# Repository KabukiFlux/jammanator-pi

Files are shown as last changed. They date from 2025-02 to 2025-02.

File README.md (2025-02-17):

# Raspberry pi jamma bard "jammanator"

<b align="center">Jammanator, the Raspberry Pi JAMMA output board 
for your cabinet</b>

## Table of contents

- [Why](#why)
- [Description](#description)
- [Schematics](#schematics)
- [Install](#install)
- [Pics and final result](#pics-and-final-result)

## Why?

This was done during some live events on Twitch.tv and tested for some time.

This is a very old design for Raspberry Pi 3B+, 4, 400, it no longer 
has the status that anybody can make money and make profit of it 
so I decided to publish it, if you have an arcade cabinet with JAMMA
a spare Raspberry Pi 3B+ or 4 and you want to have something running
then is a matter of burning the rgbpiOS or the recalboxOS and you have
everything you need to make it work.

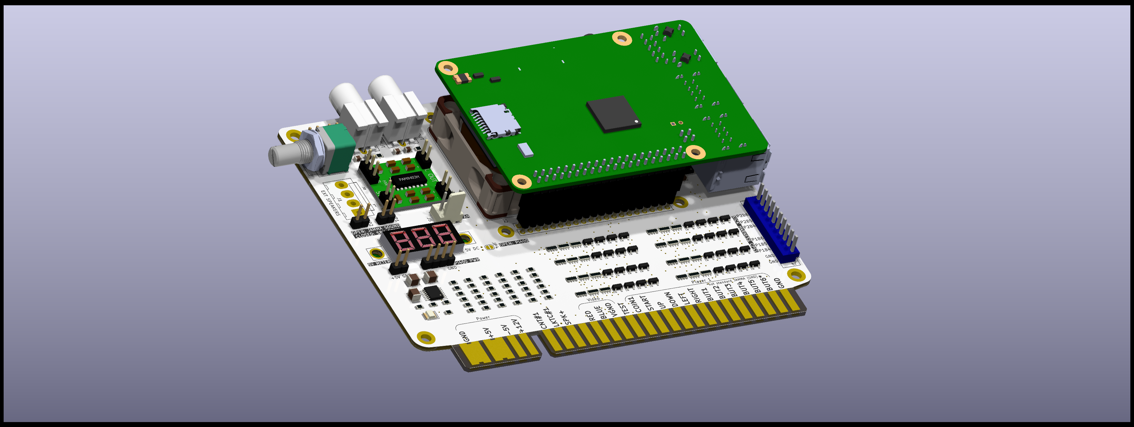
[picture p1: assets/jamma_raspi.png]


## Description

This board is intended to be a PCB used with a Raspberry Pi and a 4x4 5v fan
to remove some heat from the CPU.

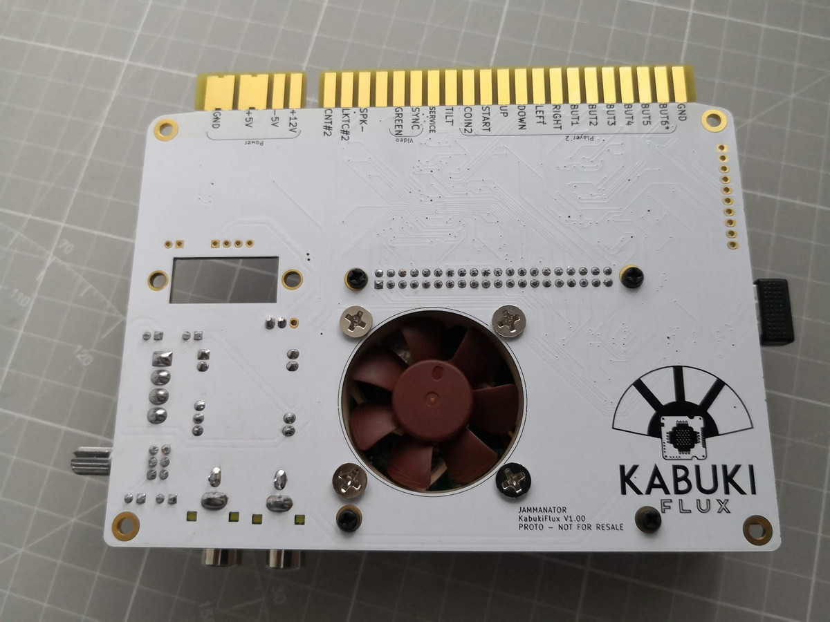
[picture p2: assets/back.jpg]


This board uses 2 I2C parallel expansion I/O chips connected to the JAMMA
connector in order to map automatically the buttons to the cabinet with no
configuration required.

A voltmeter has been added to check the 5v rail while running.

A protection circuit has been mapped to all the inputs and an extra buffer
to avoid any loss of the I2C bus, if the I2C bus is lost the Raspberry will 
no longer boot the OS (yellow led) this design will avoid that.

In the BOM directory there's an interactive BOM with all the required components.

In the gerbers directory we have the gerbers to manufacture the boards.

In the KiCAD folder we can find the KiCAD project itself.

In the circuit_js folder you can find the simulation for the I/O protection.

## Schematics

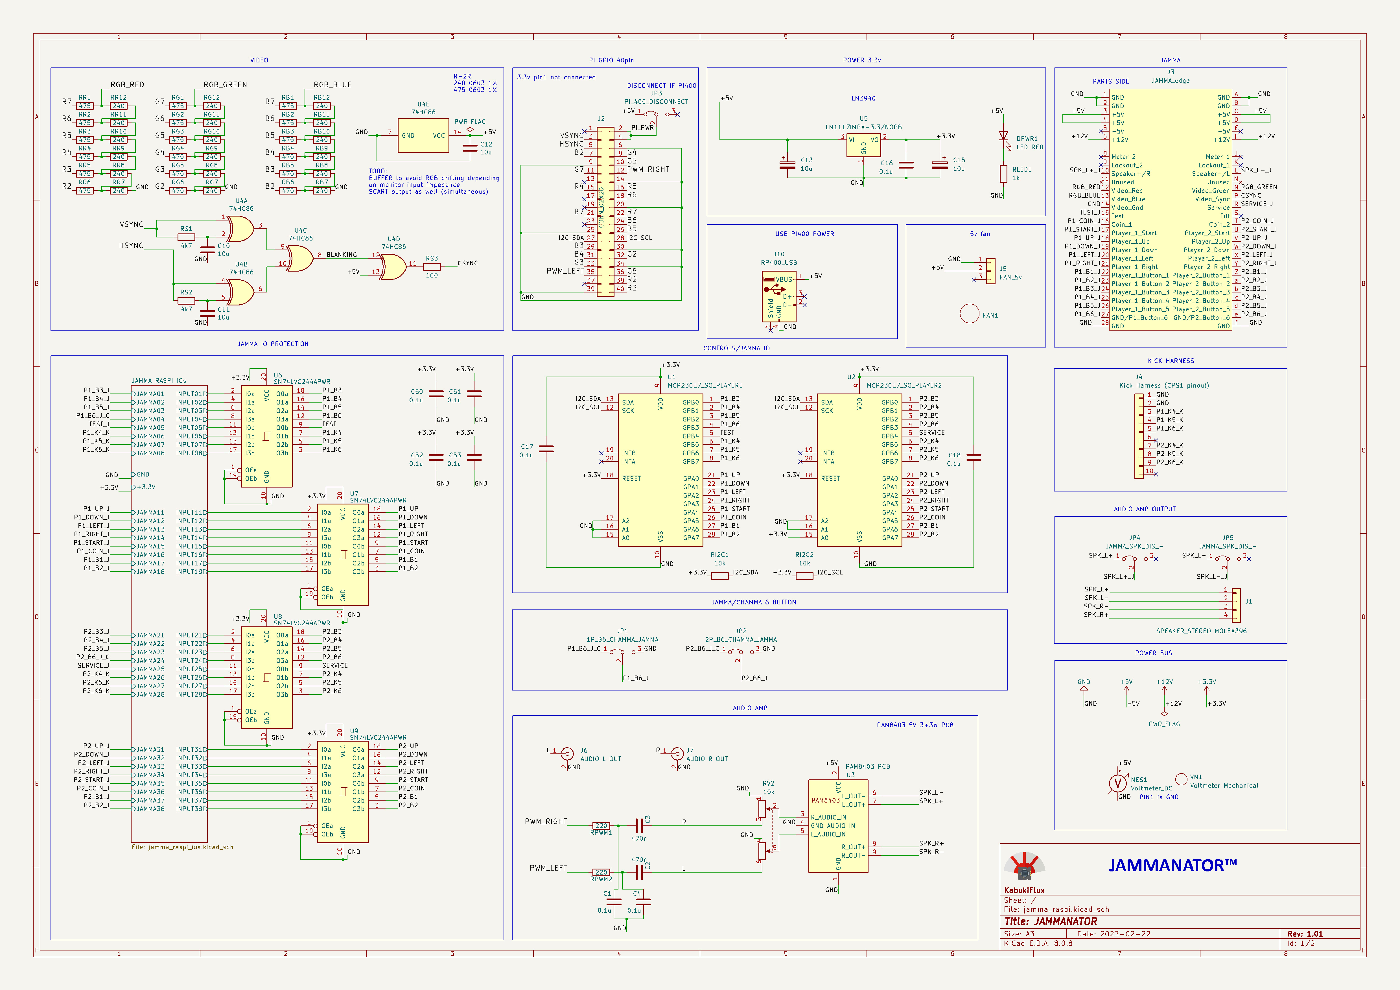
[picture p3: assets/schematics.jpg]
Schematics


This is the schematics.

## Install

If you use a Raspberry Pi 400 (the one with the keyboard) I recommend this
board and the extender in order to use it (check carefully the connector position):

- [GPIO board](https://www.amazon.es/IBest-Waveshare-Raspberry-Color-Coded-Expansion/dp/B08SK71PB4)

- [Extension cable](https://www.amazon.es/vhbw-extensi%C3%B3n-compatible-Raspberry-miniordenador/dp/B0B94KRZ8Z)

Ensure the RP400 pin is in the right position, as the RP400 cannot be powered
via the GPIO we must provide USB-C power and avoid sending power to the GPIO.

1- Send to manufacture the GERBER board to [JLCPCB](https://jlcpcb.com/) or other PCB manufacturer.

2- Get the components required, you can see here the Bill Of Materials [BOM](bom/ibom.html)

3- Solder the components.

4- Connect a Raspberry Pi with [rgbpi-OS](https://ko-fi.com/s/4119fb48b8) or 
[recalbox-OS](https://www.recalbox.com/es/download/stable/rpi/)

5- Follow the installation guide and instructions for the selected OS. 

Once finished you should have something like this:

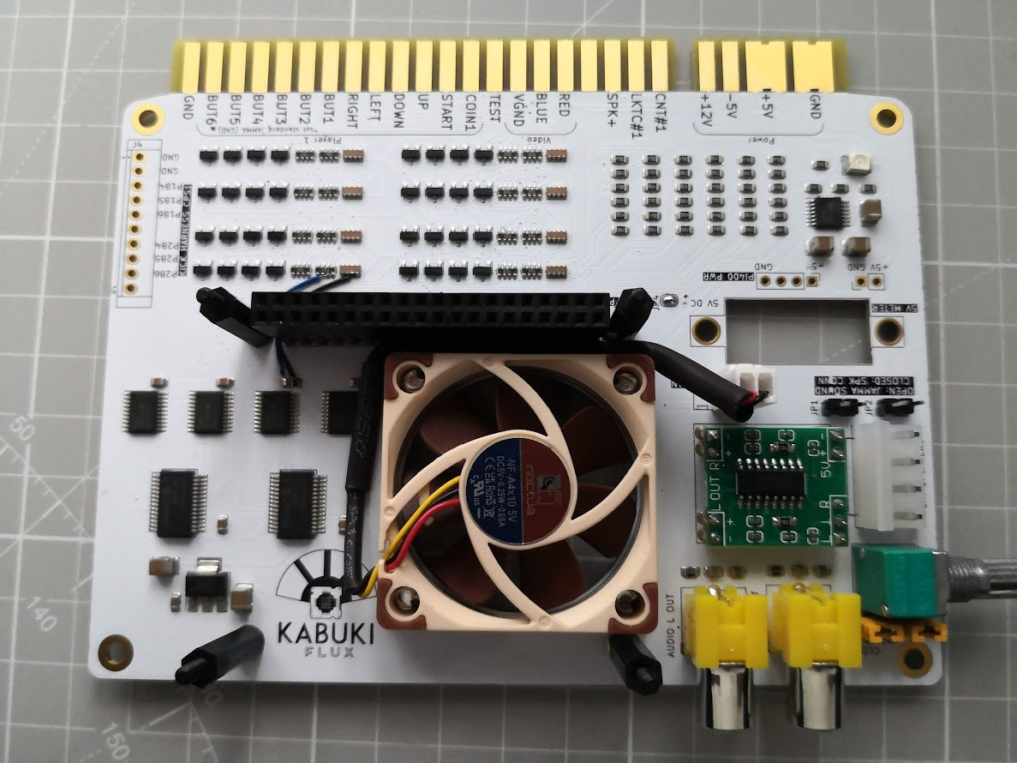
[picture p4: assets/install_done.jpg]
Install done


### Pics and final result

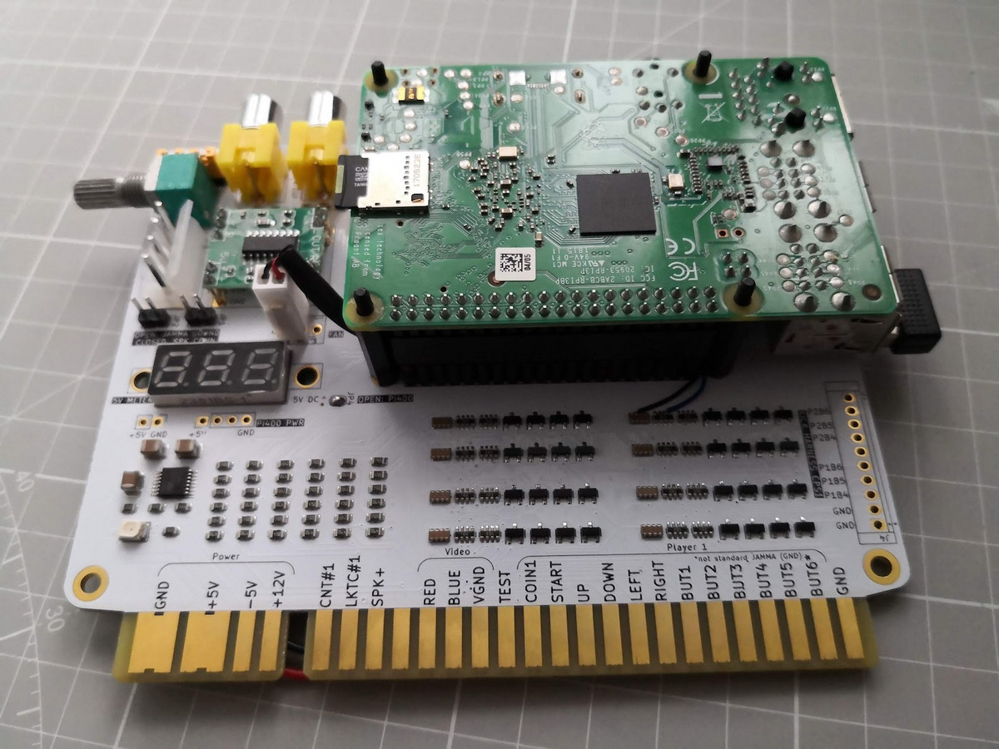
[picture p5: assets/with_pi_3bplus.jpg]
Finished


I'm not responsible
============
And yes, read below, no liability is assumed for misuse.

DISCLAIMER (See Licensing)
==========================
See LICENSE fo more information.

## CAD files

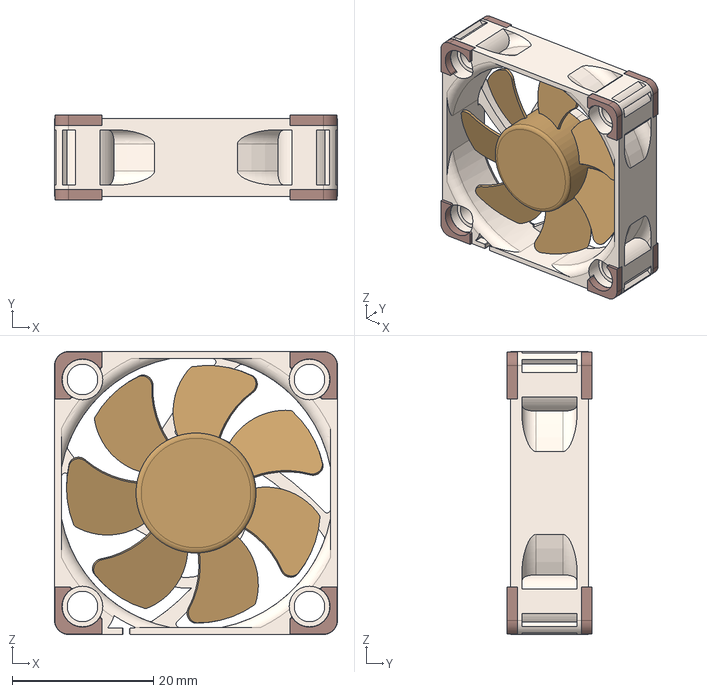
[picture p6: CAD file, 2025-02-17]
kicad/3D/Noctua_NF-A4x10_40mm.step
40.1 x 12.0 x 40.1 mm
Noctua-NF-A4x10 v1
Noctua nf-a8-pwm fan 80x80x25 v2

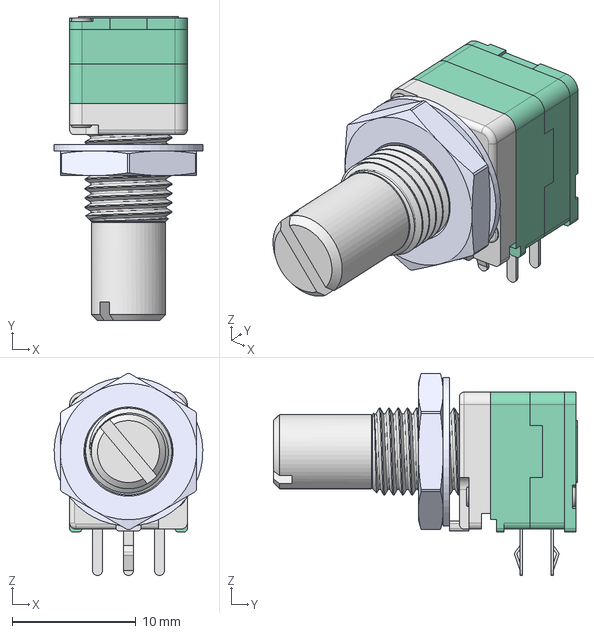
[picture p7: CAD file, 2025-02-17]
kicad/3D/RK0972-L-15RE_N-7-green.step
12.0 x 24.6 x 16.3 mm

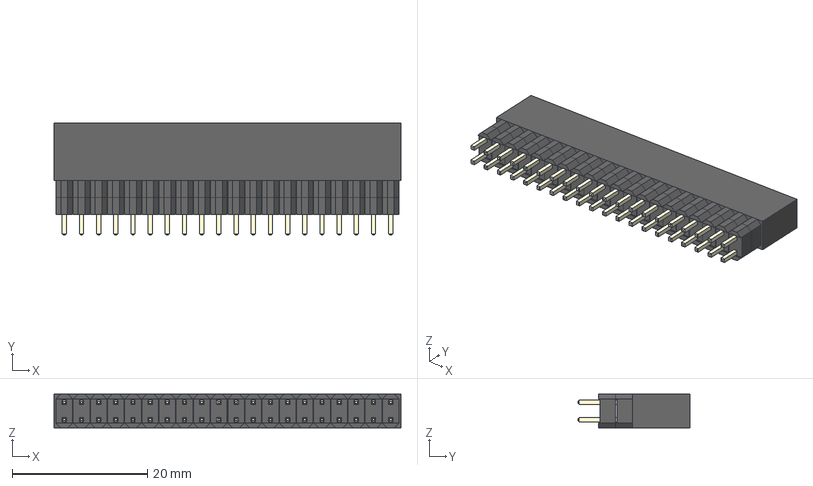
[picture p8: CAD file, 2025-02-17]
kicad/3D/PRT-14017_2x20_tall_header.stp
51.3 x 16.5 x 5.00 mm

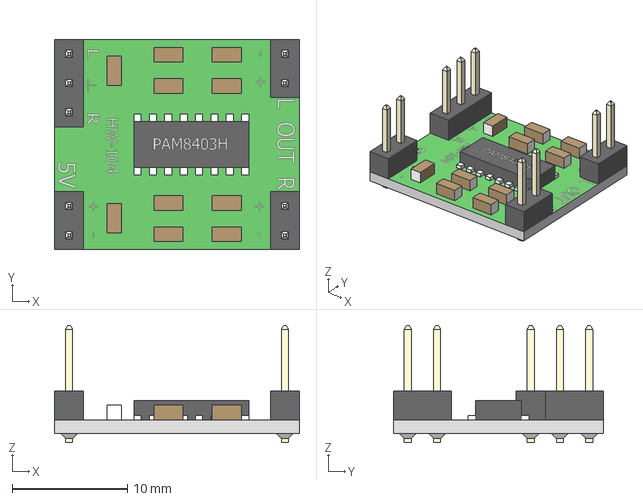
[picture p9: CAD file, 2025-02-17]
kicad/3D/Sound-Aplifier-Board-PAM8403-3W.stp
21.3 x 18.3 x 10.2 mm

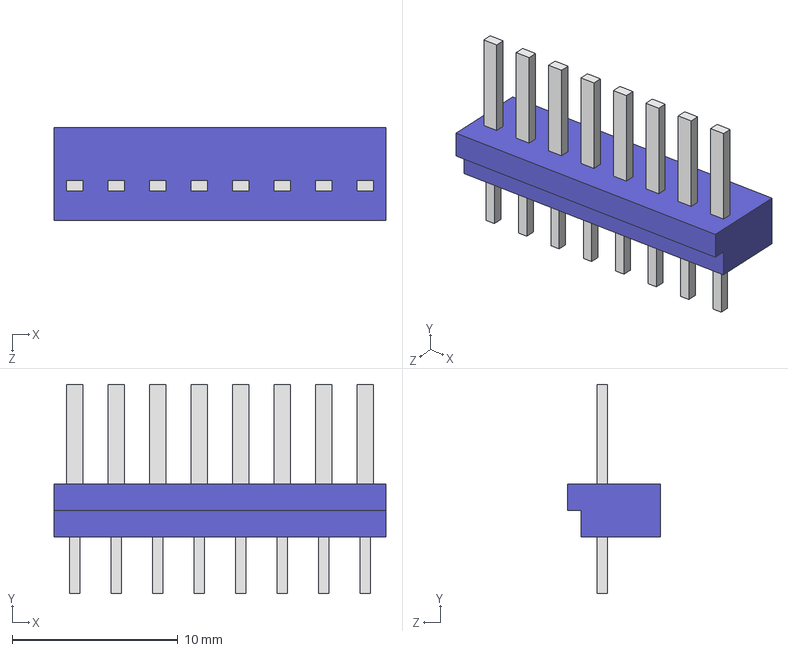
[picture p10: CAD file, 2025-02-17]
kicad/3D/B8P-SHF-1AA.STEP
20.0 x 12.6 x 5.60 mm

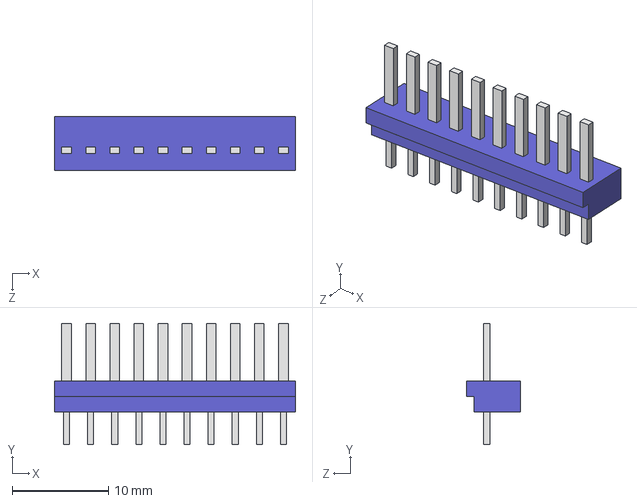
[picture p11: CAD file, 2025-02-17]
kicad/3D/B10P-SHF-1AA.STEP
25.0 x 12.6 x 5.60 mm

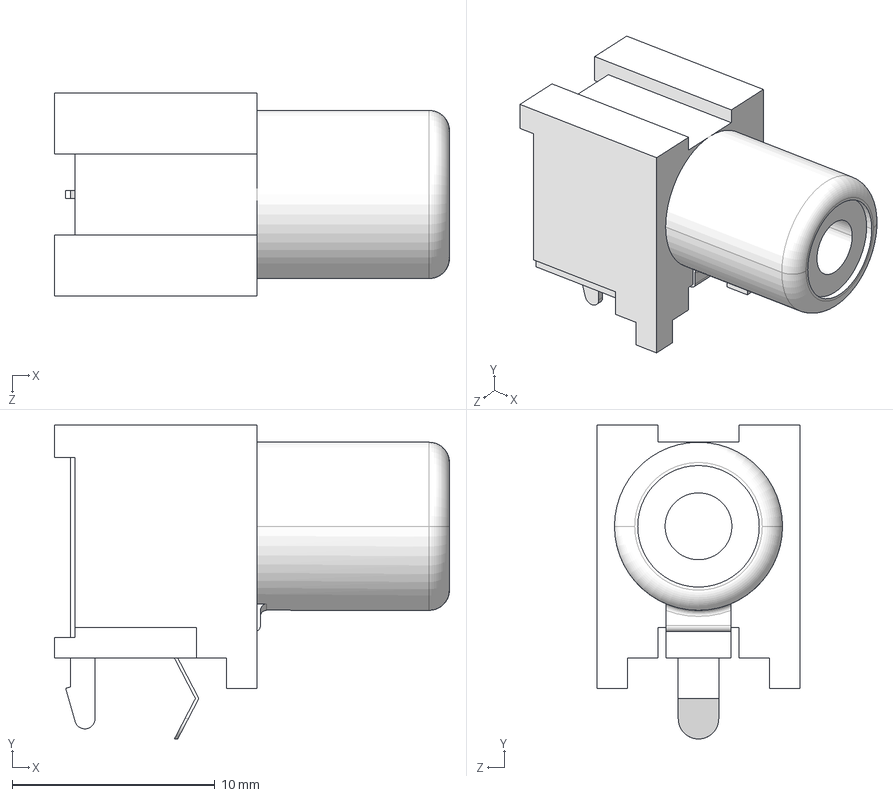
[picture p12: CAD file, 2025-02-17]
kicad/3D/CUI_DEVICES_RCJ-043.step
19.5 x 15.5 x 10.0 mm

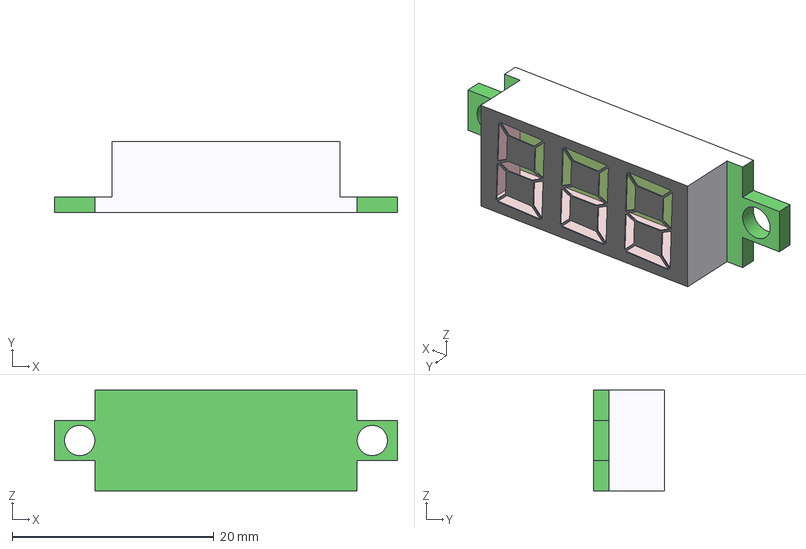
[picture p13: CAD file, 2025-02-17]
kicad/3D/Voltage_Indicator.stp
34.0 x 7.00 x 10.0 mm

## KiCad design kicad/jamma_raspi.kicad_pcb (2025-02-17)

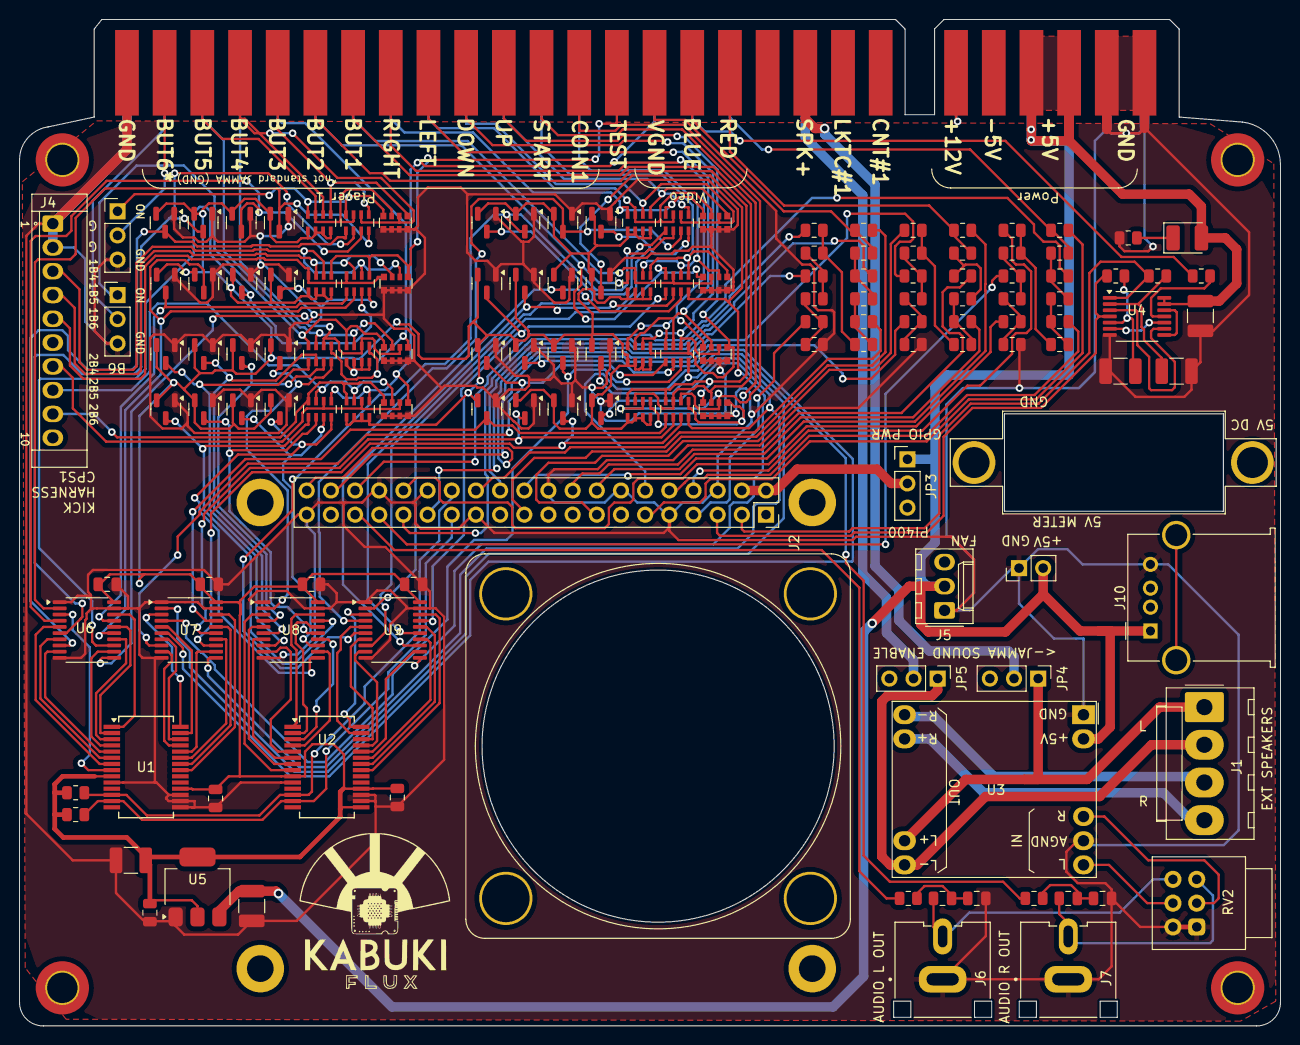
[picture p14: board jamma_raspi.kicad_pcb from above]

Board: 2 copper layers, 132.5 x 105.7 mm, 149 parts (1 on the bottom side), 165 nets.

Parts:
C1, C4, C16, C17, C18, C50, C51, C52, C53: 0.1u; C_0805_2012Metric
C2, C3: 470n; C_0805_2012Metric
C10, C11, C12, C13, C15: 10u; C_1210_3225Metric_Pad1.33x2.70mm_HandSolder
CN1, CN2, CN3, CN4, CN5, CN6, CN7, CN8: 100n; C_Array_Convex_4x0612
D1, D2, D3, D4, D5, D6, D7, D8, D9, D10, D11, D12, D13, D14, D15, D16, D17, D18, D19, D20, D21, D22, D23, D24, D25, D26, D27, D28, D29, D30, D31, D32: BAT54S; SOT-23
DPWR1: LED RED; LED_1210_3225Metric_Pad1.42x2.65mm_HandSolder
FAN1: Noctua_NF-A4x10_40mm
G1: LOGO; LogoKabuki_18mm
G2: LOGO; LogoKabuki
J1: SPEAKER_STEREO MOLEX396; Molex_KK-396_A-41791-0004_1x04_P3.96mm_Vertical
J2: CONN_02X20; GPIO_2x20_P2.54mm_Vertical_Tall_w_Standoffs
J3: JAMMA_edge
J4: Kick Harness (CPS1 pinout); B10P-SHF-1AA
J5: FAN_5v; Molex_KK-254_AE-6410-03A_1x03_P2.54mm_Vertical
J6: AUDIO L OUT; CUI_RCJ-043
J7: AUDIO R OUT; CUI_RCJ-043
J10: RP400_USB; USB_A_Molex_67643_Horizontal
JP1: 1P_B6_CHAMMA_JAMMA; PinHeader_1x03_P2.54mm_Vertical
JP2: 2P_B6_CHAMMA_JAMMA; PinHeader_1x03_P2.54mm_Vertical
JP3: PI_400_DISCONNECT; PinHeader_1x03_P2.54mm_Vertical
JP4: JAMMA_SPK_DIS_+; PinHeader_1x03_P2.54mm_Vertical
JP5: JAMMA_SPK_DIS_-; PinHeader_1x03_P2.54mm_Vertical
M1, M2, M3, M4: MountingHole_3.2mm_M3_DIN965_Pad_TopBottom
MES1: Voltmeter_DC; PinHeader_1x02_P2.54mm_Vertical
RB1, RB2, RB3, RB4, RB5, RB6: 475; R_0805_2012Metric
RB7, RB8, RB9, RB10, RB11, RB12: 240; R_0805_2012Metric
RG1, RG2, RG3, RG4, RG5, RG6: 475; R_0805_2012Metric
RG7, RG8, RG9, RG10, RG11, RG12: 240; R_0805_2012Metric
RI2C1, RI2C2: 10k; R_0805_2012Metric
RLED1: 1k; R_0805_2012Metric
RN1, RN3, RN5, RN7, RN9, RN11, RN13, RN15: 1k; R_Array_Concave_4x0603
RN2, RN4, RN6, RN8, RN10, RN12, RN14, RN16: 10k; R_Array_Concave_4x0603
RPWM1, RPWM2: 220; R_0805_2012Metric
RR1, RR2, RR3, RR4, RR5, RR6: 475; R_0805_2012Metric
RR7, RR8, RR9, RR10, RR11, RR12: 240; R_0805_2012Metric
RS1, RS2: 4k7; R_0805_2012Metric
RS3: 100; R_0805_2012Metric
RV2: 10k; Potentiometer_Alps_RK097_Dual_Horizontal
U1: MCP23017_SO_PLAYER1; SSOP-28_5.3x10.2mm_P0.65mm
U2: MCP23017_SO_PLAYER2; SSOP-28_5.3x10.2mm_P0.65mm
U3: PAM8403 PCB; PAM8403_module
U4: 74HC86; TSSOP-14_4.4x5mm_P0.65mm
U5: LM1117IMPX-3.3/NOPB; SOT-223-3_TabPin2
U6, U7, U8, U9: SN74LVC244APWR; TSSOP-20_4.4x6.5mm_P0.65mm
VM1: Voltmeter Mechanical; voltmeter

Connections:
+3.3V: C15.1, C16.1, C17.1, C18.1, C50.1, C51.1, C52.1, C53.1, D1.2 (K), D2.2 (K), D3.2 (K), D4.2 (K), D5.2 (K), D6.2 (K), D7.2 (K), D8.2 (K), D9.2 (K), D10.2 (K), D11.2 (K), D12.2 (K), D13.2 (K), D14.2 (K), D15.2 (K), D16.2 (K), D17.2 (K), D18.2 (K), D19.2 (K), D20.2 (K), D21.2 (K), D22.2 (K), D23.2 (K), D24.2 (K), D25.2 (K), D26.2 (K), D27.2 (K), D28.2 (K), D29.2 (K), D30.2 (K), D31.2 (K), D32.2 (K), RI2C1.1, RI2C2.1, RN2.5 (R4.2), RN2.6 (R3.2), RN2.7 (R2.2), RN2.8 (R1.2), RN4.5 (R4.2), RN4.6 (R3.2), RN4.7 (R2.2), RN4.8 (R1.2), RN6.5 (R4.2), RN6.6 (R3.2), RN6.7 (R2.2), RN6.8 (R1.2), RN8.5 (R4.2), RN8.6 (R3.2), RN8.7 (R2.2), RN8.8 (R1.2), RN10.5 (R4.2), RN10.6 (R3.2), RN10.7 (R2.2), RN10.8 (R1.2), RN12.5 (R4.2), RN12.6 (R3.2), RN12.7 (R2.2), RN12.8 (R1.2), RN14.5 (R4.2), RN14.6 (R3.2), RN14.7 (R2.2), RN14.8 (R1.2), RN16.5 (R4.2), RN16.6 (R3.2), RN16.7 (R2.2), RN16.8 (R1.2), U1.9 (VDD), U1.18 (~RESET), U2.9 (VDD), U2.15 (A0), U2.18 (~RESET), U5.2 (VO), U6.20 (VCC), U7.20 (VCC), U8.20 (VCC), U9.20 (VCC)
+5V: C12.1, C13.1, DPWR1.2 (A), J3.3 (+5V), J3.4 (+5V), J3.C (+5V), J3.D (+5V), J5.2, J10.1 (VBUS), JP3.1 (A), MES1.2 (+), U3.2 (VCC), U4.13, U4.14 (VCC), U5.3 (VI)
+12V: J3.6 (+12V), J3.F (+12V)
/B2: J2.7, RB6.1
/B3: J2.29, RB5.1
/B4: J2.31, RB4.1
/B5: J2.26, RB3.1
/B6: J2.24, RB2.1
/B7: J2.21, RB1.1
/BLANKING: U4.8, U4.12
/CSYNC: J3.P (Video_Sync), RS3.1
/G2: J2.32, RG6.1
/G3: J2.33, RG5.1
/G4: J2.8, RG4.1
/G5: J2.10, RG3.1
/G6: J2.36, RG2.1
/G7: J2.11, RG1.1
/HSYNC: J2.5, RS2.2, U4.4
/I2C_SCL: J2.28, RI2C2.2, U1.12 (SCK), U2.12 (SCK)
/I2C_SDA: J2.27, RI2C1.2, U1.13 (SDA), U2.13 (SDA)
/JAMMA RASPI IOs/INPUT01: D1.3 (COM), RN1.8 (R1.2), U6.2 (I0a)
/JAMMA RASPI IOs/INPUT02: D2.3 (COM), RN1.7 (R2.2), U6.4 (I1a)
/JAMMA RASPI IOs/INPUT03: D3.3 (COM), RN1.6 (R3.2), U6.6 (I2a)
/JAMMA RASPI IOs/INPUT04: D4.3 (COM), RN1.5 (R4.2), U6.8 (I3a)
/JAMMA RASPI IOs/INPUT05: D5.3 (COM), RN3.8 (R1.2), U6.11 (I0b)
/JAMMA RASPI IOs/INPUT06: D6.3 (COM), RN3.7 (R2.2), U6.13 (I1b)
/JAMMA RASPI IOs/INPUT07: D7.3 (COM), RN3.6 (R3.2), U6.15 (I2b)
/JAMMA RASPI IOs/INPUT08: D8.3 (COM), RN3.5 (R4.2), U6.17 (I3b)
/JAMMA RASPI IOs/INPUT11: D9.3 (COM), RN5.8 (R1.2), U7.2 (I0a)
/JAMMA RASPI IOs/INPUT12: D10.3 (COM), RN5.7 (R2.2), U7.4 (I1a)
/JAMMA RASPI IOs/INPUT13: D11.3 (COM), RN5.6 (R3.2), U7.6 (I2a)
/JAMMA RASPI IOs/INPUT14: D12.3 (COM), RN5.5 (R4.2), U7.8 (I3a)
/JAMMA RASPI IOs/INPUT15: D13.3 (COM), RN7.8 (R1.2), U7.11 (I0b)
/JAMMA RASPI IOs/INPUT16: D14.3 (COM), RN7.7 (R2.2), U7.13 (I1b)
/JAMMA RASPI IOs/INPUT17: D15.3 (COM), RN7.6 (R3.2), U7.15 (I2b)
/JAMMA RASPI IOs/INPUT18: D16.3 (COM), RN7.5 (R4.2), U7.17 (I3b)
/JAMMA RASPI IOs/INPUT21: D17.3 (COM), RN9.8 (R1.2), U8.2 (I0a)
/JAMMA RASPI IOs/INPUT22: D18.3 (COM), RN9.7 (R2.2), U8.4 (I1a)
/JAMMA RASPI IOs/INPUT23: D19.3 (COM), RN9.6 (R3.2), U8.6 (I2a)
/JAMMA RASPI IOs/INPUT24: D20.3 (COM), RN9.5 (R4.2), U8.8 (I3a)
/JAMMA RASPI IOs/INPUT25: D21.3 (COM), RN11.8 (R1.2), U8.11 (I0b)
/JAMMA RASPI IOs/INPUT26: D22.3 (COM), RN11.7 (R2.2), U8.13 (I1b)
/JAMMA RASPI IOs/INPUT27: D23.3 (COM), RN11.6 (R3.2), U8.15 (I2b)
/JAMMA RASPI IOs/INPUT28: D24.3 (COM), RN11.5 (R4.2), U8.17 (I3b)
/JAMMA RASPI IOs/INPUT31: D25.3 (COM), RN13.8 (R1.2), U9.2 (I0a)
/JAMMA RASPI IOs/INPUT32: D26.3 (COM), RN13.7 (R2.2), U9.4 (I1a)
/JAMMA RASPI IOs/INPUT33: D27.3 (COM), RN13.6 (R3.2), U9.6 (I2a)
/JAMMA RASPI IOs/INPUT34: D28.3 (COM), RN13.5 (R4.2), U9.8 (I3a)
/JAMMA RASPI IOs/INPUT35: D29.3 (COM), RN15.8 (R1.2), U9.11 (I0b)
/JAMMA RASPI IOs/INPUT36: D30.3 (COM), RN15.7 (R2.2), U9.13 (I1b)
/JAMMA RASPI IOs/INPUT37: D31.3 (COM), RN15.6 (R3.2), U9.15 (I2b)
/JAMMA RASPI IOs/INPUT38: D32.3 (COM), RN15.5 (R4.2), U9.17 (I3b)
/L: C2.1, J6.1 (In), RV2.6
/P1_B1: U1.27 (GPA6), U7.5 (O2b)
/P1_B1_J: CN4.3 (R3.1), J3.22 (Player_1_Button_1), RN7.3 (R3.1), RN8.3 (R3.1)
/P1_B2: U1.28 (GPA7), U7.3 (O3b)
/P1_B2_J: CN4.4 (R4.1), J3.23 (Player_1_Button_2), RN7.4 (R4.1), RN8.4 (R4.1)
/P1_B3: U1.1 (GPB0), U6.18 (O0a)
/P1_B3_J: CN1.1 (R1.1), J3.24 (Player_1_Button_3), RN1.1 (R1.1), RN2.1 (R1.1)
/P1_B4: U1.2 (GPB1), U6.16 (O1a)
/P1_B4_J: CN1.2 (R2.1), J3.25 (Player_1_Button_4), RN1.2 (R2.1), RN2.2 (R2.1)
/P1_B5: U1.3 (GPB2), U6.14 (O2a)
/P1_B5_J: CN1.3 (R3.1), J3.26 (Player_1_Button_5), RN1.3 (R3.1), RN2.3 (R3.1)
/P1_B6: U1.4 (GPB3), U6.12 (O3a)
/P1_B6_J: J3.27 (GND/P1_Button_6), JP1.2 (C)
/P1_B6_J_C: CN1.4 (R4.1), JP1.1 (A), RN1.4 (R4.1), RN2.4 (R4.1)
/P1_COIN: U1.26 (GPA5), U7.7 (O1b)
/P1_COIN_J: CN4.2 (R2.1), J3.16 (Coin_1), RN7.2 (R2.1), RN8.2 (R2.1)
/P1_DOWN: U1.22 (GPA1), U7.16 (O1a)
/P1_DOWN_J: CN3.2 (R2.1), J3.19 (Player_1_Down), RN5.2 (R2.1), RN6.2 (R2.1)
/P1_K4: U1.6 (GPB5), U6.7 (O1b)
/P1_K4_K: CN2.2 (R2.1), J4.3, RN3.2 (R2.1), RN4.2 (R2.1)
/P1_K5: U1.7 (GPB6), U6.5 (O2b)
/P1_K5_K: CN2.3 (R3.1), J4.4, RN3.3 (R3.1), RN4.3 (R3.1)
/P1_K6: U1.8 (GPB7), U6.3 (O3b)
/P1_K6_K: CN2.4 (R4.1), J4.5, RN3.4 (R4.1), RN4.4 (R4.1)
/P1_LEFT: U1.23 (GPA2), U7.14 (O2a)
/P1_LEFT_J: CN3.3 (R3.1), J3.20 (Player_1_Left), RN5.3 (R3.1), RN6.3 (R3.1)
/P1_RIGHT: U1.24 (GPA3), U7.12 (O3a)
/P1_RIGHT_J: CN3.4 (R4.1), J3.21 (Player_1_Right), RN5.4 (R4.1), RN6.4 (R4.1)
/P1_START: U1.25 (GPA4), U7.9 (O0b)
/P1_START_J: CN4.1 (R1.1), J3.17 (Player_1_Start), RN7.1 (R1.1), RN8.1 (R1.1)
/P1_UP: U1.21 (GPA0), U7.18 (O0a)
/P1_UP_J: CN3.1 (R1.1), J3.18 (Player_1_Up), RN5.1 (R1.1), RN6.1 (R1.1)
/P2_B1: U2.27 (GPA6), U9.5 (O2b)
/P2_B1_J: CN8.3 (R3.1), J3.Z (Player_2_Button_1), RN15.3 (R3.1), RN16.3 (R3.1)
/P2_B2: U2.28 (GPA7), U9.3 (O3b)
/P2_B2_J: CN8.4 (R4.1), J3.a (Player_2_Button_2), RN15.4 (R4.1), RN16.4 (R4.1)
/P2_B3: U2.1 (GPB0), U8.18 (O0a)
/P2_B3_J: CN5.1 (R1.1), J3.b (Player_2_Button_3), RN9.1 (R1.1), RN10.1 (R1.1)
/P2_B4: U2.2 (GPB1), U8.16 (O1a)
/P2_B4_J: CN5.2 (R2.1), J3.c (Player_2_Button_4), RN9.2 (R2.1), RN10.2 (R2.1)
/P2_B5: U2.3 (GPB2), U8.14 (O2a)
/P2_B5_J: CN5.3 (R3.1), J3.d (Player_2_Button_5), RN9.3 (R3.1), RN10.3 (R3.1)
/P2_B6: U2.4 (GPB3), U8.12 (O3a)
/P2_B6_J: J3.e (GND/P2_Button_6), JP2.2 (C)
/P2_B6_J_C: CN5.4 (R4.1), JP2.1 (A), RN9.4 (R4.1), RN10.4 (R4.1)
/P2_COIN: U2.26 (GPA5), U9.7 (O1b)
/P2_COIN_J: CN8.2 (R2.1), J3.T (Coin_2), RN15.2 (R2.1), RN16.2 (R2.1)
/P2_DOWN: U2.22 (GPA1), U9.16 (O1a)
/P2_DOWN_J: CN7.2 (R2.1), J3.W (Player_2_Down), RN13.2 (R2.1), RN14.2 (R2.1)
/P2_K4: U2.6 (GPB5), U8.7 (O1b)
/P2_K4_K: CN6.2 (R2.1), J4.7, RN11.2 (R2.1), RN12.2 (R2.1)
/P2_K5: U2.7 (GPB6), U8.5 (O2b)
/P2_K5_K: CN6.3 (R3.1), J4.8, RN11.3 (R3.1), RN12.3 (R3.1)
/P2_K6: U2.8 (GPB7), U8.3 (O3b)
/P2_K6_K: CN6.4 (R4.1), J4.9, RN11.4 (R4.1), RN12.4 (R4.1)
/P2_LEFT: U2.23 (GPA2), U9.14 (O2a)
/P2_LEFT_J: CN7.3 (R3.1), J3.X (Player_2_Left), RN13.3 (R3.1), RN14.3 (R3.1)
/P2_RIGHT: U2.24 (GPA3), U9.12 (O3a)
/P2_RIGHT_J: CN7.4 (R4.1), J3.Y (Player_2_Right), RN13.4 (R4.1), RN14.4 (R4.1)
/P2_START: U2.25 (GPA4), U9.9 (O0b)
/P2_START_J: CN8.1 (R1.1), J3.U (Player_2_Start), RN15.1 (R1.1), RN16.1 (R1.1)
/P2_UP: U2.21 (GPA0), U9.18 (O0a)
/P2_UP_J: CN7.1 (R1.1), J3.V (Player_2_Up), RN13.1 (R1.1), RN14.1 (R1.1)
/PI_PWR: J2.2, J2.4, JP3.2 (C)
/PWM_LEFT: J2.35, RPWM2.1
/PWM_RIGHT: J2.12, RPWM1.1
/R: C3.1, J7.1 (In), RV2.3
/R2: J2.38, RR6.1
/R3: J2.40, RR5.1
/R4: J2.15, RR4.1
/R5: J2.16, RR3.1
/R6: J2.18, RR2.1
/R7: J2.22, RR1.1
/RGB_BLUE: J3.13 (Video_Blue), RB1.2, RB12.1
/RGB_GREEN: J3.N (Video_Green), RG1.2, RG12.1
/RGB_RED: J3.12 (Video_Red), RR1.2, RR12.1
/SERVICE: U2.5 (GPB4), U8.9 (O0b)
/SERVICE_J: CN6.1 (R1.1), J3.R (Service), RN11.1 (R1.1), RN12.1 (R1.1)
/SPK_L+: J1.1, JP4.1 (A), U3.7 (L_OUT+)
/SPK_L+_J: J3.10 (Speaker+/R), JP4.2 (C)
/SPK_L-: J1.2, JP5.1 (A), U3.6 (L_OUT-)
/SPK_L-_J: J3.L (Speaker-/L), JP5.2 (C)
/SPK_R+: J1.4, U3.8 (R_OUT+)
/SPK_R-: J1.3, U3.9 (R_OUT-)
/TEST: U1.5 (GPB4), U6.9 (O0b)
/TEST_J: CN2.1 (R1.1), J3.15 (Test), RN3.1 (R1.1), RN4.1 (R1.1)
/VSYNC: J2.3, RS1.2, U4.1
GND: C1.2, C4.2, C10.2, C11.2, C12.2, C13.2, C15.2, C16.2, C17.2, C18.2, C50.2, C51.2, C52.2, C53.2, CN1.5 (R4.2), CN1.6 (R3.2), CN1.7 (R2.2), CN1.8 (R1.2), CN2.5 (R4.2), CN2.6 (R3.2), CN2.7 (R2.2), CN2.8 (R1.2), CN3.5 (R4.2), CN3.6 (R3.2), CN3.7 (R2.2), CN3.8 (R1.2), CN4.5 (R4.2), CN4.6 (R3.2), CN4.7 (R2.2), CN4.8 (R1.2), CN5.5 (R4.2), CN5.6 (R3.2), CN5.7 (R2.2), CN5.8 (R1.2), CN6.5 (R4.2), CN6.6 (R3.2), CN6.7 (R2.2), CN6.8 (R1.2), CN7.5 (R4.2), CN7.6 (R3.2), CN7.7 (R2.2), CN7.8 (R1.2), CN8.5 (R4.2), CN8.6 (R3.2), CN8.7 (R2.2), CN8.8 (R1.2), D1.1 (A), D2.1 (A), D3.1 (A), D4.1 (A), D5.1 (A), D6.1 (A), D7.1 (A), D8.1 (A), D9.1 (A), D10.1 (A), D11.1 (A), D12.1 (A), D13.1 (A), D14.1 (A), D15.1 (A), D16.1 (A), D17.1 (A), D18.1 (A), D19.1 (A), D20.1 (A), D21.1 (A), D22.1 (A), D23.1 (A), D24.1 (A), D25.1 (A), D26.1 (A), D27.1 (A), D28.1 (A), D29.1 (A), D30.1 (A), D31.1 (A), D32.1 (A), J2.6, J2.9, J2.14, J2.20, J2.25, J2.30, J2.34, J2.39, J3.1 (GND), J3.2 (GND), J3.14 (Video_Gnd), J3.28 (GND), J3.A (GND), J3.B (GND), J3.f (GND), J4.1, J4.2, J5.1, J6.2 (Ext), J7.2 (Ext), J10.4 (GND), JP1.3 (B), JP2.3 (B), MES1.1 (-), RB7.2, RG7.2, RLED1.2, RR7.2, RV2.1, RV2.4, U1.10 (VSS), U1.15 (A0), U1.16 (A1), U1.17 (A2), U2.10 (VSS), U2.16 (A1), U2.17 (A2), U3.1 (GND), U3.4 (GND_AUDIO_IN), U4.7 (GND), U5.1 (GND), U6.1 (OEa), U6.10 (GND), U6.19 (OEb), U7.1 (OEa), U7.10 (GND), U7.19 (OEb), U8.1 (OEa), U8.10 (GND), U8.19 (OEb), U9.1 (OEa), U9.10 (GND), U9.19 (OEb)
unnamed: C1.1, C3.2, RPWM1.2
unnamed: C2.2, C4.1, RPWM2.2
unnamed: C10.1, RS1.1, U4.2
unnamed: C11.1, RS2.1, U4.5
unnamed: DPWR1.1 (K), RLED1.1
unnamed: RB5.2, RB8.1, RB9.2
unnamed: RB6.2, RB7.1, RB8.2
unnamed: RB3.2, RB10.1, RB11.2
unnamed: RB4.2, RB9.1, RB10.2
unnamed: RB2.2, RB11.1, RB12.2
unnamed: RG5.2, RG8.1, RG9.2
unnamed: RG6.2, RG7.1, RG8.2
unnamed: RG3.2, RG10.1, RG11.2
unnamed: RG4.2, RG9.1, RG10.2
unnamed: RG2.2, RG11.1, RG12.2
unnamed: RR5.2, RR8.1, RR9.2
unnamed: RR6.2, RR7.1, RR8.2
unnamed: RR3.2, RR10.1, RR11.2
unnamed: RR4.2, RR9.1, RR10.2
unnamed: RR2.2, RR11.1, RR12.2
unnamed: RS3.2, U4.11
unnamed: RV2.5, U3.5 (L_AUDIO_IN)
unnamed: RV2.2, U3.3 (R_AUDIO_IN)
unnamed: U4.3, U4.9
unnamed: U4.6, U4.10
